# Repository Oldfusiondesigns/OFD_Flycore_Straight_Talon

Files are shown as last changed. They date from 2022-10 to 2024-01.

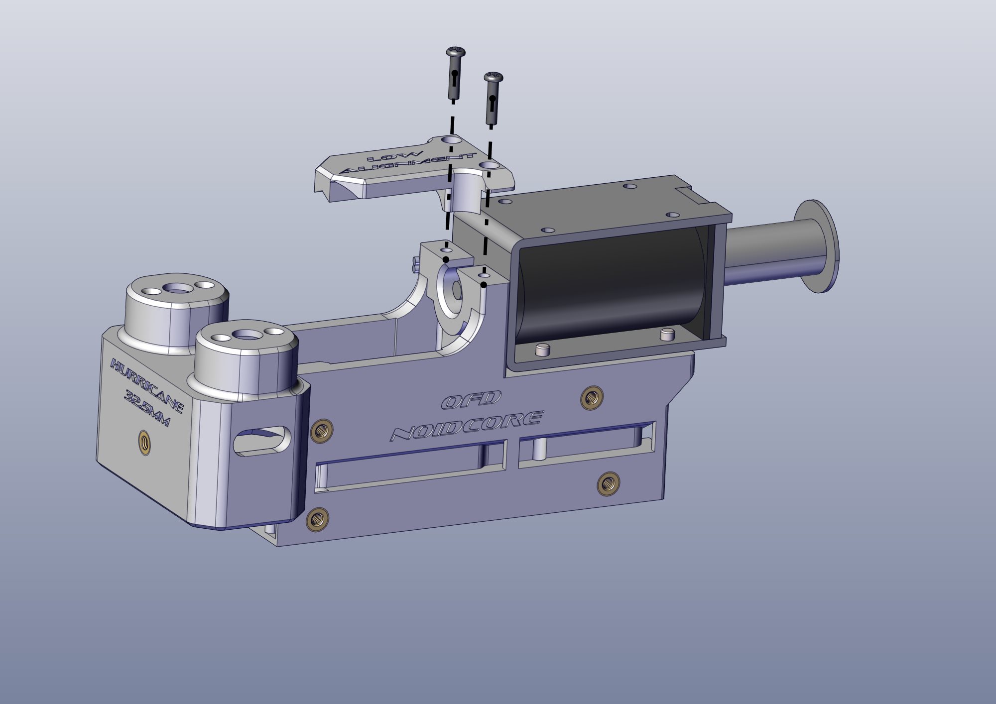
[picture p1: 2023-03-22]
Images/dart guide.jpg

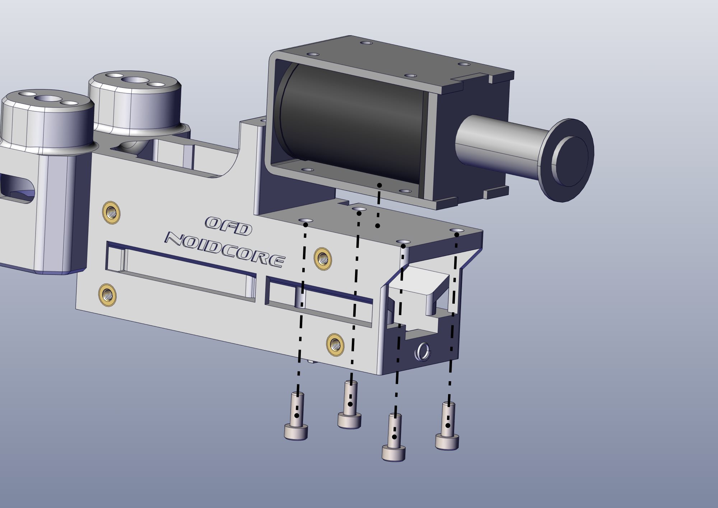
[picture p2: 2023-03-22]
Images/noid install.jpg

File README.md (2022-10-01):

**What is Flycore?**

· Flycore is a 90% complete blaster awaiting your
new shell, design, or integration! I’ve done all
the work on flywheel spacing, pusher
mechanisms, and even a complete magwell with
detent or release!

· The goal of Flycore is to allow designers new
and old to focus on creating exciting new
designs with a proven flywheel core that’s
simple to build and has compact geometry to
integrate

**Details**

· Compatible with ANY Flywheel (From FTW to
Banned Blasters)

· Angled Flycore compatible with BOTH Angled and Slim Angled
Talons (Nightingale mags) with the same mag
release/detent

·	Straight Flycore compatible with Talons and Tachi magazines

· Takes N20 Pushers (ROF from 300rpm/5dps up
to 3000rpm/50dps)(Recommended 2000rpm and under for best performance)

· Rear pusher position switch for controllable rate
of fire (wiring similar to 3 switch rapidstrike)

· Compatible with any 130 profile motor (can fit
132, 180s)

· Experimental topload capability

· Full steps provided to create your own new and
exciting blasters!

**Licensing and
Production**

· Flycore is license under CC-BY-SA-NC

· You have permission to print as many as you
like for yourself, and remix the files in any way
you like, but you CANNOT sell files or prints
without my permission or coming to an
agreement.

· If you wish to sell, please contact me so we can
arrange a licensing fee for a small percentage of
sale price

**Hardware List**

(2) 130 motors

(1) N20 Pusher Motor of your choice! (300-
3000rpm)

(4) m2x5mm motor screws

(8-9) M3 x 5mm diameter x 6mm deep heat set inserts (longer ones may not work)

(6) M2.6x12mm toy screws

(1) M2.6x10mm toy screw (Optional)

(1) Cherry DB2 style switch for pusher position
(Optional)

(1) Spring 20mm in length less than 7mm in diameter for mag release (Recommend McMaster 9657K297 Trimmed to ~20-22mm)

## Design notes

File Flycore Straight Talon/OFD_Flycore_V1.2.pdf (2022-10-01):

# OFD

# FLYCORE

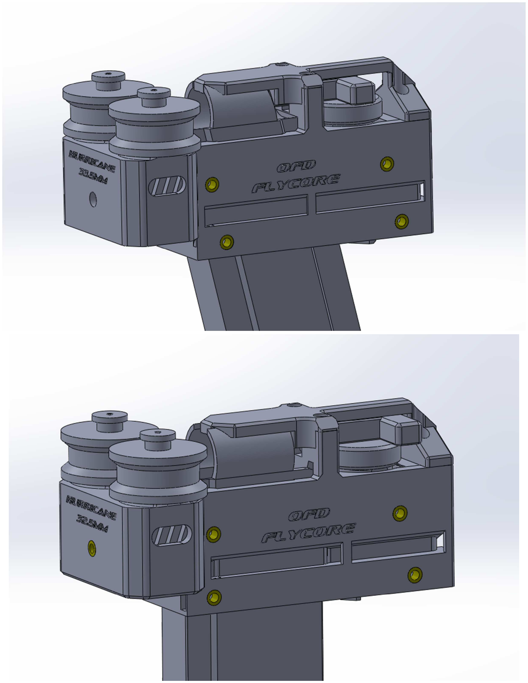
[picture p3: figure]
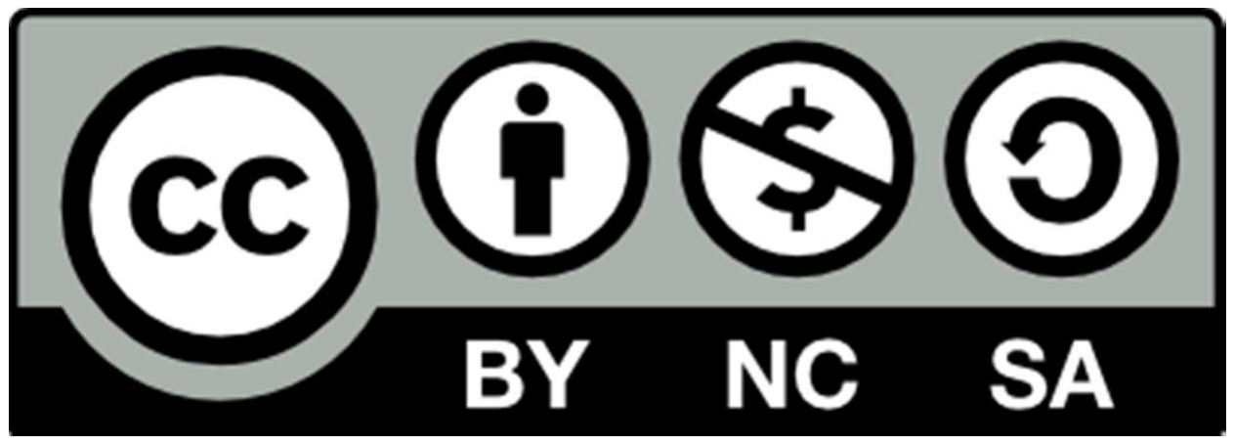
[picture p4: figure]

What is Flycore?
- Flycore is a 90% complete blaster awaiting your new shell, design, or integration! I’ve done all the work on flywheel spacing, pusher mechanisms, and even a complete magwell with detent or release!
- The goal of Flycore is to allow designers new and old to focus on creating exciting new designs with a proven flywheel core that’s simple to build and has compact geometry to integrate

Details
- Compatible with ANY Flywheel (From FTW to Banned Blasters)
- Angled Flycore compatible with BOTH Angled and Slim Angled Talons (Nightingale mags) with the same mag release/detent
- Straight Flycore compatible with Talons and Tachi magazines
- Takes N20 Pushers (ROF from 300rpm/5dps up to 3000rpm/50dps) (Recommended 2000rpm and under for best performance)
- Rear pusher position switch for controllable rate of fire (wiring similar to 3 switch rapidstrike)
- Compatible with any 130 profile motor (can fit 132, 180s)
- Experimental topload capability
- Full steps provided to create your own new and exciting blasters!

Licensing and
Production
- Flycore is licensed under CC-BY-SA-NC: https://creativecommons.org/licenses/by-nc-sa/2.0/
- You have permission to print as many as you like for yourself, and remix the files in any way you like with attribution, but you CANNOT sell files or prints without my permission or coming to an agreement.

Hardware List

(2) 130 motors
(1) N20 Pusher Motor of your choice! (300-3000rpm)
(4) m2x5mm motor screws
(8-9) M3 x 5mm diameter x 6mm deep heat set inserts (longer ones may not work)
(6) M2.6x12mm toy screws
(1) M2.6x10mm toy screw (Optional)
(1) Cherry DB2 style switch for pusher position (Optional)
(1) Spring 20mm in length less than 7mm in diameter for mag release (Recommend McMaster 9657K297 Trimmed to ~20-22mm)

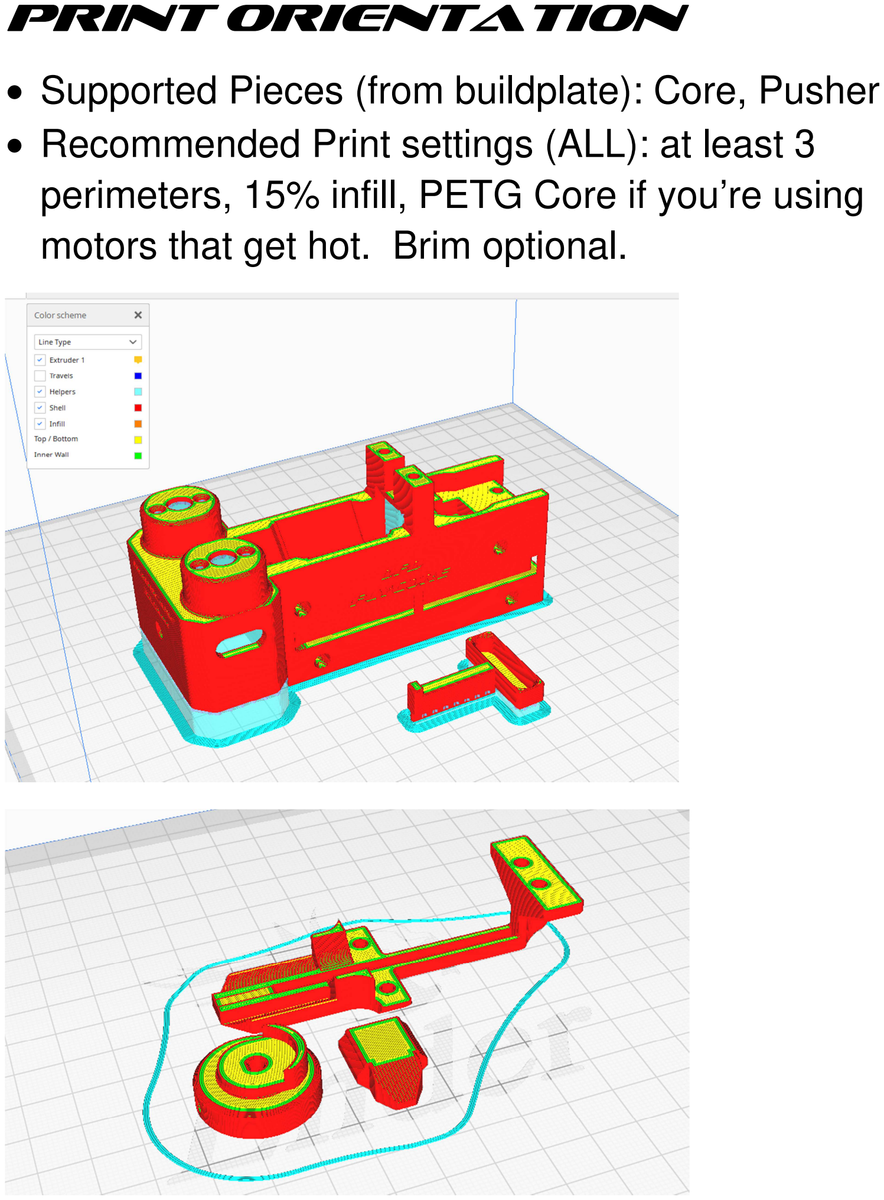
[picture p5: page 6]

Print Orientation
- Supported Pieces (from buildplate): Core, Pusher
- Recommended Print settings (ALL): at least 3 perimeters, 15% infill, PETG Core if you’re using motors that get hot. Brim optional.

Assembly

Step 1: Install heatsets

TIP: Trim off any flashing inside and outside the core to prevent installation issues

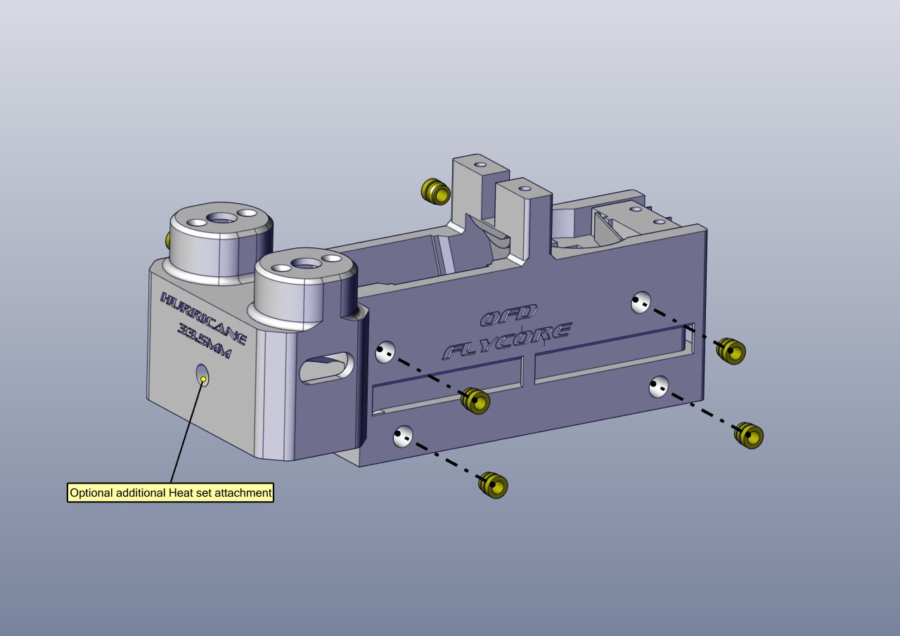
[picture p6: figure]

Step 2: Install N20

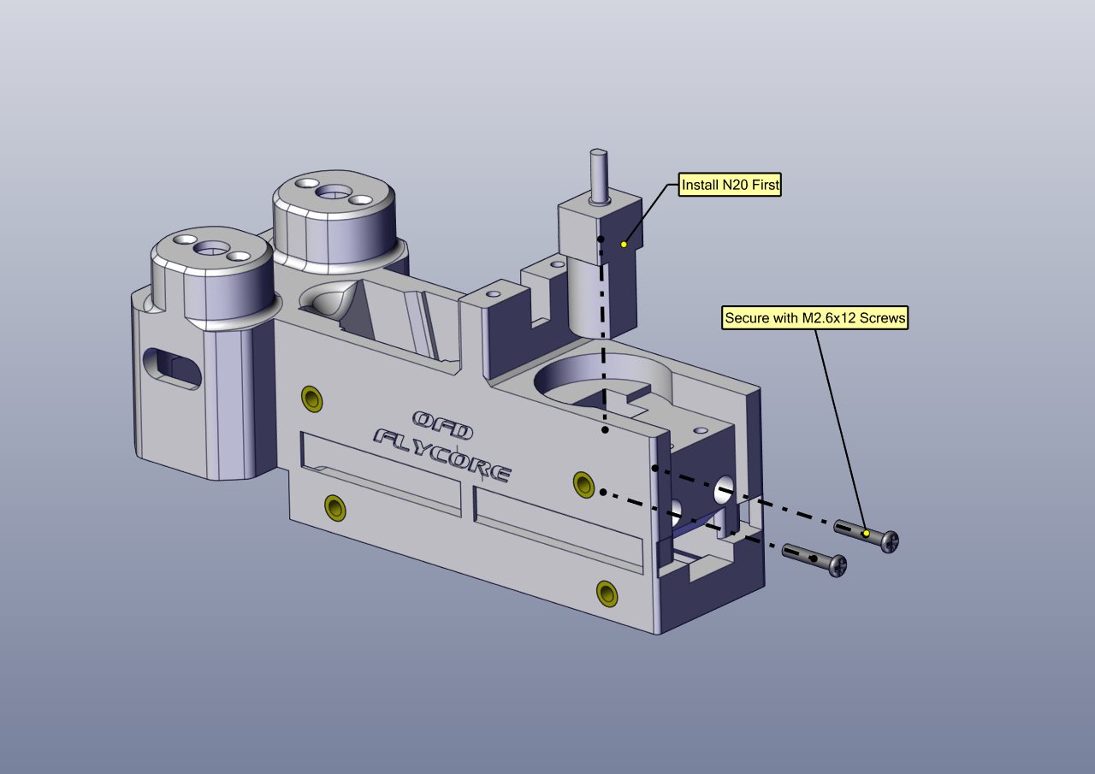
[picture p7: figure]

Step 3: Install Pusher Wheel

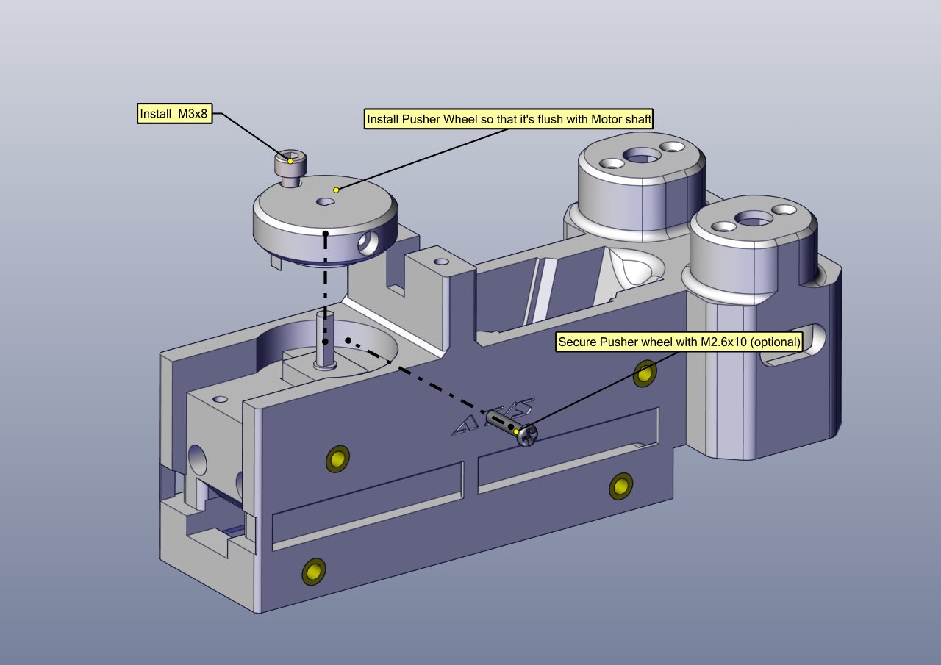
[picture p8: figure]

Step 4: Pusher Assembly Installation

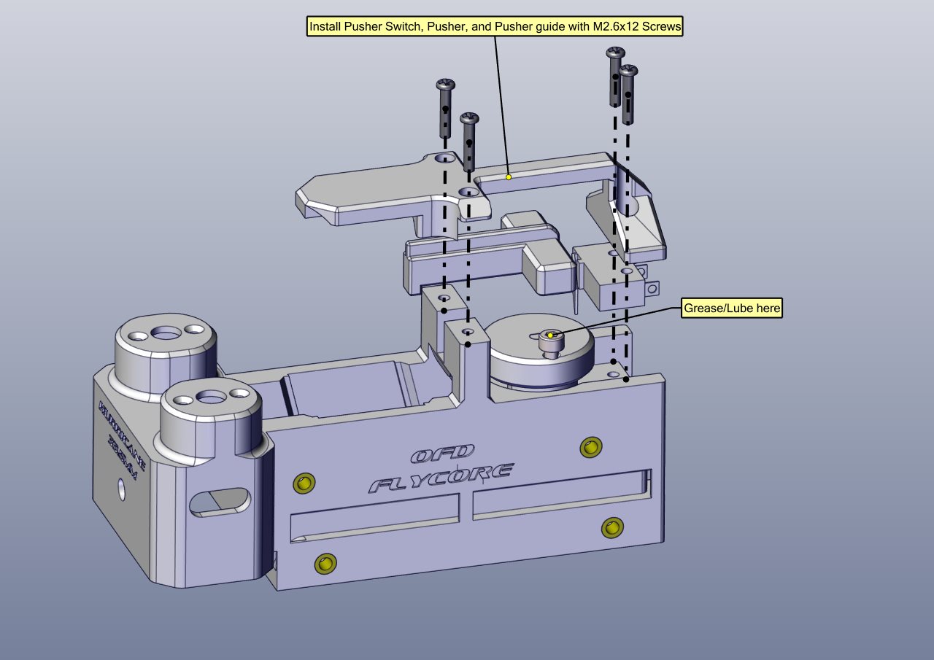
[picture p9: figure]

Step 5: Mag Release Installation

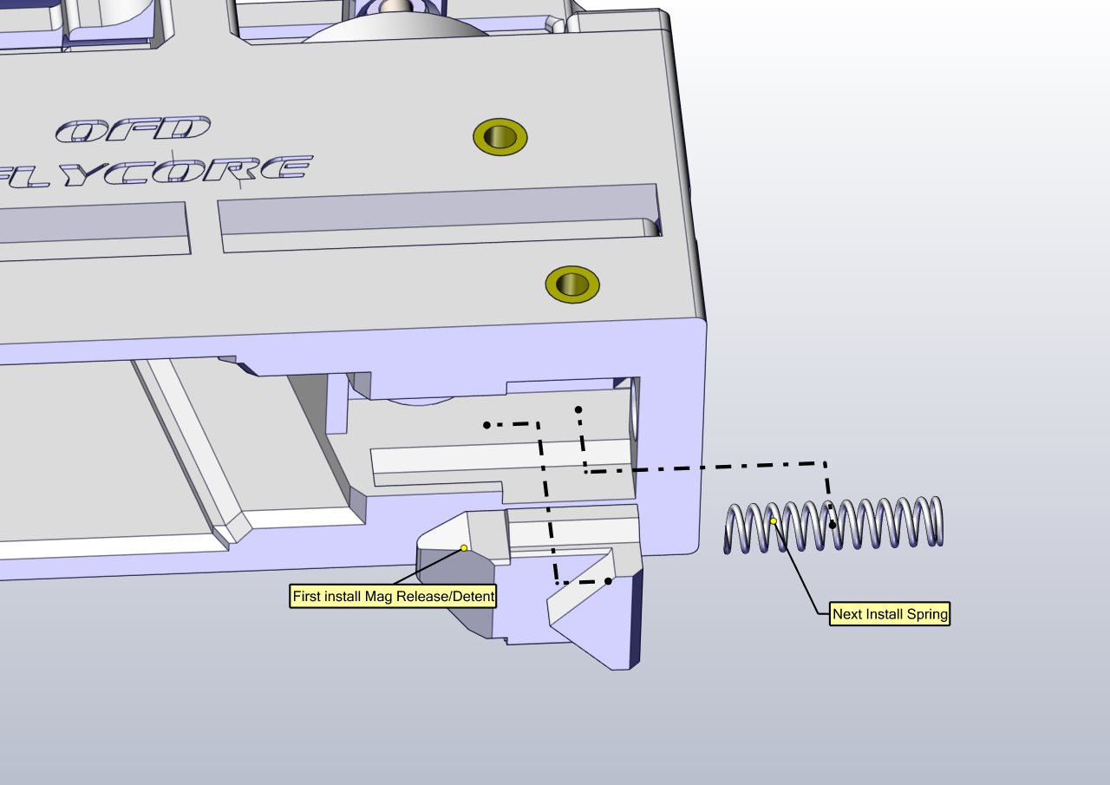
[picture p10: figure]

Step 6: Motor and Flywheel Installation

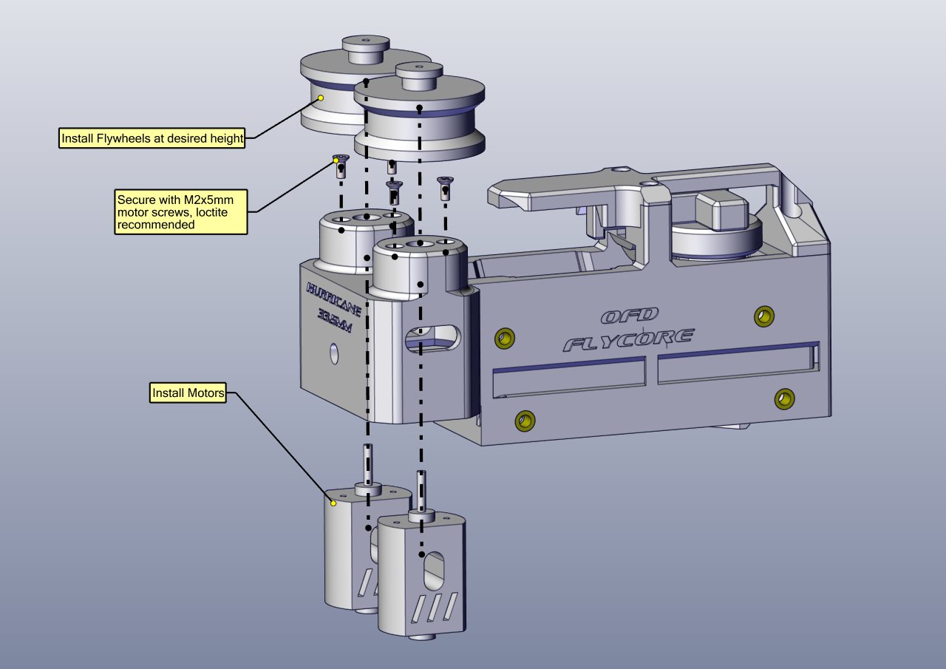
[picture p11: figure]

FAQ
- My N20 doesn’t seem like it’s activating the pusher switch!
a)If this is the case, bend the N20 switch arm slightly outward until it activates the switch when the pusher is fully back
- My 2000 or 3000 rpm pusher is running away, or won’t brake when I release the trigger!
a)In my testing these motors don’t have enough torque to overcome their own inertia and brake within a cycle, so if you want to run this high ROF, I’d recommend not worrying about including a pusher switch.
- My slim angled talons aren’t feeding right!
a)In our testing, slim angled talons can be picky about darts and magazine cleanliness, especially at higher rates of fire, so YMMV!
- I have more questions, or my questions aren’t listed here!
a)No worries! Feel free to reach out to me on Etsy, or my discord: ag04#6231

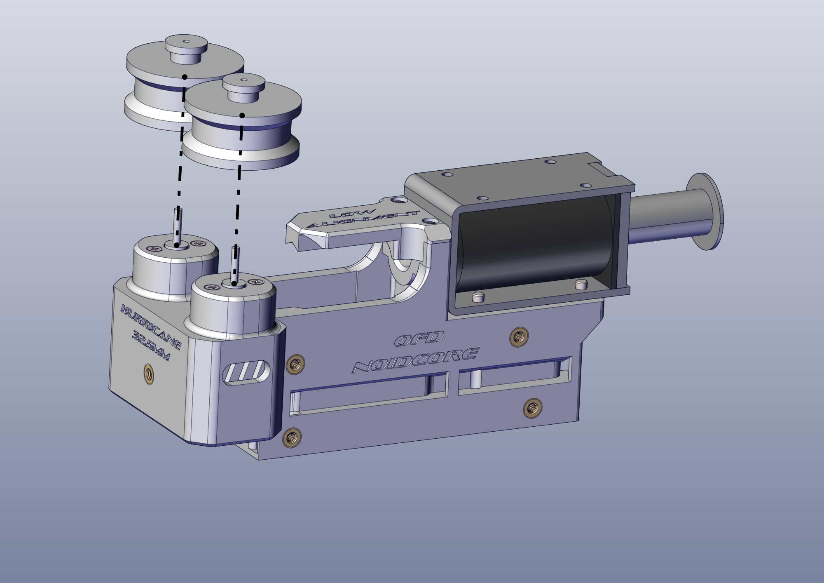
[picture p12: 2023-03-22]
Images/wheels.jpg

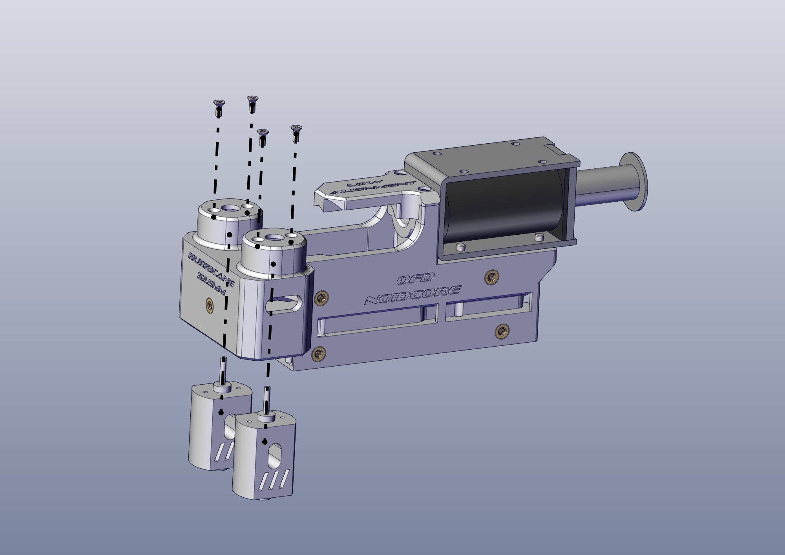
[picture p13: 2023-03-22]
Images/motor screws.jpg

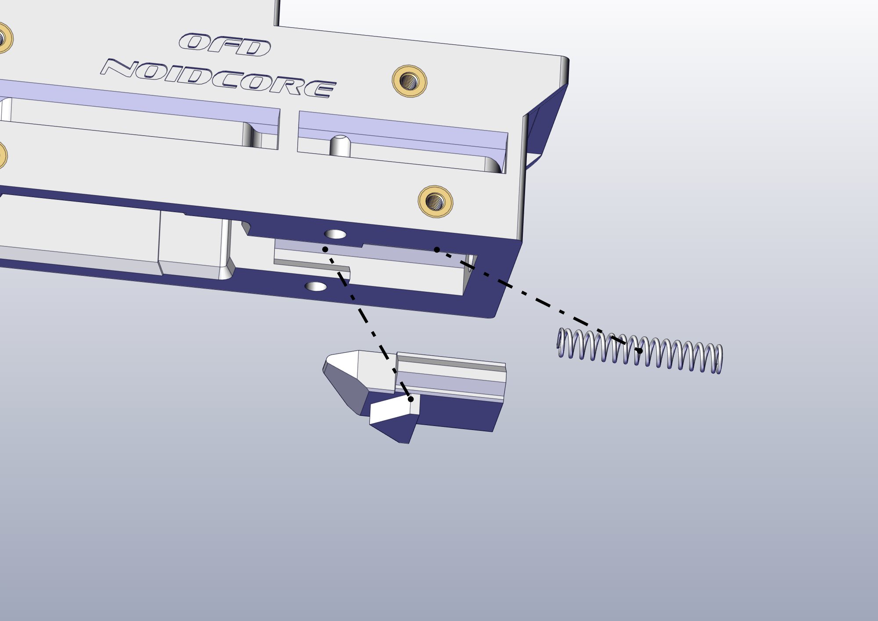
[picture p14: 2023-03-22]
Images/spring detent.jpg

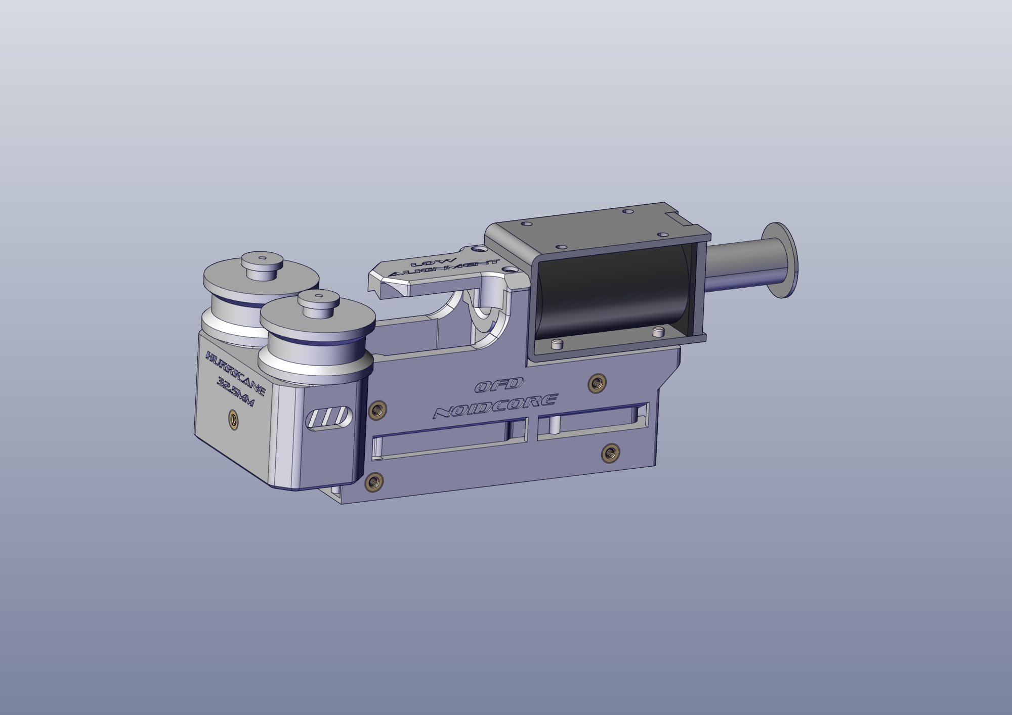
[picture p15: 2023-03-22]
Images/OFD_NOIDCORE_HURR_STRAIGHT_V1.jpg

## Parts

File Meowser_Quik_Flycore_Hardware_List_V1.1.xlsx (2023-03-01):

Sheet: Revision tracking
Changelog
Revision | Date | Changes
V1.0 | 2022-10-14 | Initial Release
V1.1 | 2023-03-01 | BOM corrections, additions, verification

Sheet: Flycore Angled+Straight
FLYCORE ANGLED/STRAIGHT BOM (NO BLASTER)
Priority | Category | Part | Qty | Description
REQUIRED | HARDWARE | M3 Heatsets (5-5.4mm Dia, <6.5mm length) | 9 | (8) Quik (9) Meowser
 |  | M3x8mm Socket Head Cap Screw | 1 | N20 Pusher wheel set screw
 |  | M2x4-5mm motor screws | 4 | Motor screws
 |  | M2.6x10mm toy screws | 1 | Pusher wheel set screw
 |  | M2.6x12mm toy screws | 6 | (4) pusher guide (2) optional N20 motor set screws
 |  | Mcmaster 9657k297 Trimmed to 20-22mm OR alt part 9657K282(pending update) | 1 | Mag release spring
 | ELECTRONICS | 130-180 motors | 2 | 130 Motors for best vent fitment
 |  | Cherry DB2 style switch with lever | 1 | Pusher postion switch
 |  | N20 Pusher Motor | 1 | Recommend under 1000 rpm and under for live center and 2000 rpm for highest reliable ROF

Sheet: Meowser
MEOWSER BOM (NO FLYCORE)
Priority | Category | Part | Qty | Description
REQUIRED | HARDWARE | M2x4-5mm motor screws | 4 | Rear sight, Volt meter
 |  | M2.6x12mm Toy Screws | 4 | Muzzle on square barrel, Mag release, Switch pack
 |  | M3x8mm Socket Head Cap Screws | 14 | (9) body, (3) barrel
 |  | M3x6-8mm Button Head Screw | 1 | LH Grip
 |  | M3x8-10mm Battery door screw | 1 | Battery Door
 |  | M3 Heatsets (5-5.4mm Dia, <6.5mm length) | 5 | (3) Barrel (2) Grip/Batt door
 |  | Mcmaster 9657k297 Trimmed to 20-22mm OR alt part 9657K282(pending update) | 1 | Trigger Spring
 | ELECTRONICS | 21A Omron style switch without Lever | 1 | Rev switch
 |  | Cherry DB2 style switch without lever | 1 | Pusher switch
 |  | 22 Ga wire | 1 | Pusher, Trigger Switch
 |  | 18 Ga wire | 1 | Motors, Rev Switch, Battery
 |  | XT30 connector | 1 | Battery Connector
 |  | Heatshrink | 1 | Heatshrink for xt30
OPTIONAL | HARDWARE | M3x12 Socket Head Cap Screws | 4 | Fidlock Mounts
 |  | .078"/2mm Fiber optic | 1
 |  | Fidlock M | 2 | approx 50mm total for sights
 | ELECTRONICS | .28" Battery Voltage meter | 1
OPTIONAL DL-44 Kit | HARDWARE | M3x12 Socket Head Cap Screws | 4 | Scope mounting plate
 |  | M3 Heatsets | 2 | Scope mount assembly
 |  | M3x8-10mm thumb screws OR M3x8 Socket Head Cap Screws | 2 | Scope mount side
 |  | M3x8 Socket Head Cap Screws | 6 | (4) Scope rings (2) upper mount
OPTIONAL Tactical Kit | HARDWARE | M2x4-5mm motor screws | 1 | Printed RMR reticle set screw
 |  | M3x8 Socket Head Cap Screws | 2 | Printed RMR

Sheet: Flycore+Meowser
MEOWSER + FLYCORE STRAIGHT BOM
Priority | Category | Part | Qty | Description
REQUIRED | HARDWARE | M2x4-5mm motor screws | 8 | (2) Rear sight, (2)Volt meter/blank plate (4) Motors
 |  | M2.6x10mm toy screws | 1 | N20 pusher wheel set screw
 |  | M2.6x12mm toy Screws | 10 | (2) Muzzle on square barrel, (4) Flycore pusher guide, (2) N20 Set screws, (1) Mag release (1) Switch pack
 |  | M3x8mm Socket Head Cap Screws | 13 | (9) body, (3) barrel (1) Flycore Pusher Wheel
 |  | M3x6-8mm Button Head Screw | 1 | RH Grip
 |  | M3x8-10mm Battery door thumb screw | 1 | Battery Door
 |  | M3 Heatsets (5-5.4mm Dia, <6.5mm length) | 14 | (9) Flycore Straight (3) Barrel (2) Grip/Batt door
 |  | Mcmaster 9657k297 Trimmed to 20-22mm OR alt part 9657K282(pending update) | 2 | Trigger Spring, Flycore mag release
 | ELECTRONICS | 130-180 motors | 2 | 130 Motors for best vent fitment
 |  | N20 Pusher Motor | 1 | Recommend 1000 rpm and under for live center and 2000 rpm for highest reliable ROF (2k untested on high ROF Tachis)
 |  | 21A Omron style switch without Lever | 1 | Rev switch
 |  | Cherry DB2 style switch without lever | 1 | Pusher switch
 |  | Cherry DB2 style switch with lever | 1 | Pusher postion switch
 |  | 22 Ga wire | 1 | Pusher, Trigger Switch
 |  | 18 Ga wire | 1 | Motors, Rev Switch, Battery
 |  | XT30 connector | 1 | Battery Connector
 |  | Heatshrink | 1 | Heatshrink for xt30
OPTIONAL | HARDWARE | M3x12 Socket Head Cap Screws | 4 | Fidlock Mounts
 |  | .078"/2mm Fiber optic | 1 | approx 50mm total for sights
 |  | Fidlock M | 2
 | ELECTRONICS | .28" Battery Voltage meter | 1
OPTIONAL DL-44 Kit | HARDWARE | M3x12 Socket Head Cap Screws | 4 | Scope mounting plate
 |  | M3 Heatsets | 2 | Scope mount assembly
 |  | M3x8-10mm thumb screws OR M3x8 Socket Head Cap Screws | 2 | Scope mount side
 |  | M3x8 Socket Head Cap Screws | 6 | (4) Scope rings (2) upper mount
OPTIONAL Tactical Kit | HARDWARE | M2x4-5 motor screw | 1 | Printed RMR reticle set screw
 |  | M3x8 Socket Head Cap Screws | 2 | Printed RMR

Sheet: Quik
QUIK BOM (NO FLYCORE)
Priority | CATEGORY | Part | Qty | Description
REQUIRED | HARDWARE | M2x4-5mm motor screws | 2 | Rear sight
 |  | M2.6x12mm Toy Screws | 1 | switch plate
 |  | M3x8mm Socket Head Cap Screws | 9 | (8) body, (1) switch plate
 |  | M3x8-10mm Battery door screw | 1 | Battery Door
 |  | M3 Heatsets (5-5.4mm Dia, <6.5mm length) | 2 | (1) switch plate (1) batt door
 |  | Mcmaster 9657k297 Trimmed to 20-22mm | 1 | Trigger Spring
 | ELECTRONICS | 21A Omron style switch without Lever | 1 | Rev switch
 |  | Cherry DB2 style switch with lever | 1 | Pusher switch
 |  | 22 Ga wire | 1 | Pusher, Trigger Switch
 |  | 18 Ga wire | 1 | Motors, Rev Switch, Battery
 |  | XT30 connector | 1 | Battery Connector
 |  | Heatshrink | 1 | Heatshrink for xt30
OPTIONAL | HARDWARE | M3x12 Socket Head Cap Screws | 4 | Fidlock Mounts
 |  | Fidlock M | 2
 | ELECTRONICS | .28" Battery Voltage meter | 1

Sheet: Flycore+Quik
QUIK + FLYCORE ANGLED BOM
Priority | Category | Part | Qty | Description
REQUIRED | HARDWARE | M2x4-5mm motor screws | 6 | (2) Rear sight, (4) Motor screws
 |  | M2.6x10mm toy screws | 1 | N20 pusher wheel set screw
 |  | M2.6x12mm Toy Screws | 1 | (4) pusher guide (2) optional n20 set screws (1) switch plate
 |  | M3x8mm Socket Head Cap Screws | 10 | (8) body, (1) switch plate (1) Flycore pusher wheel
 |  | M3x8-10mm battery door thumb screw | 1 | Battery Door
 |  | M3 Heatsets (5-5.4mm Dia, <6.5mm length) | 10 | (1) switch plate (1) batt door (8) Flycore Angled
 |  | Mcmaster 9657k297 Trimmed to 20-22mm OR alt part 9657K282(pending update) | 2 | (1) Trigger spring (1) Mag release spring
 | ELECTRONICS | 130-180 motors | 2 | 130 Motors for best vent fitment
 |  | N20 Pusher Motor | 1 | Recommend 1000 rpm and under for live center and 2000 rpm max for highest reliable ROF
 |  | 21A Omron style switch without Lever | 1 | Rev switch
 |  | Cherry DB2 style switch with lever | 2 | (1) Pusher switch (1) Trigger switch
 |  | 22 Ga wire | 1 | Pusher, Trigger Switch
 |  | 18 Ga wire | 1 | Motors, Rev Switch, Battery
 |  | XT30 connector | 1 | Battery Connector
 |  | Heatshrink | 1 | Heatshrink for xt30
OPTIONAL | HARDWARE | M3x12 Socket Head Cap Screws | 4 | Fidlock Mounts
 |  | Fidlock M | 2
 | ELECTRONICS | .28" Battery Voltage meter | 1

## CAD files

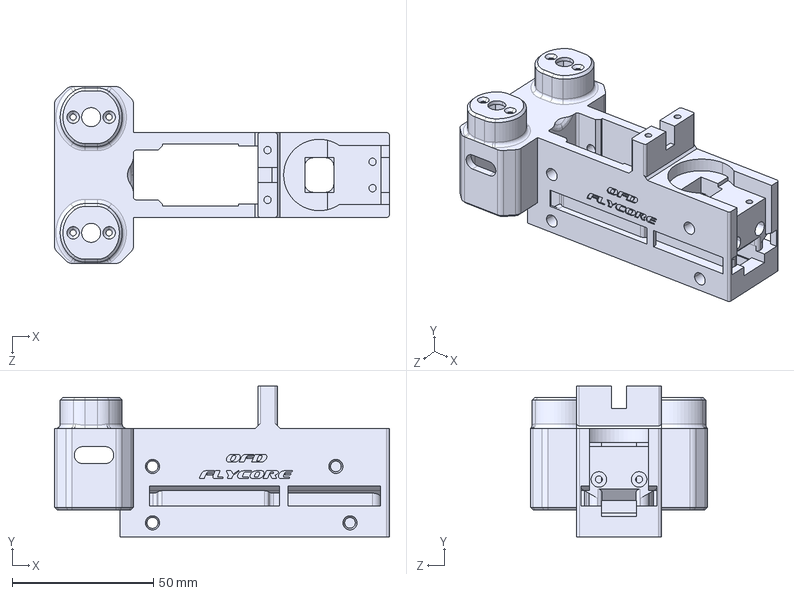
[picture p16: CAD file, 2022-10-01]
Flycore Straight Talon/STEPs/OFD_FLYCORE_STRAIGHT_FULL_41MM_V1.STEP
118.8 x 53.5 x 62.7 mm

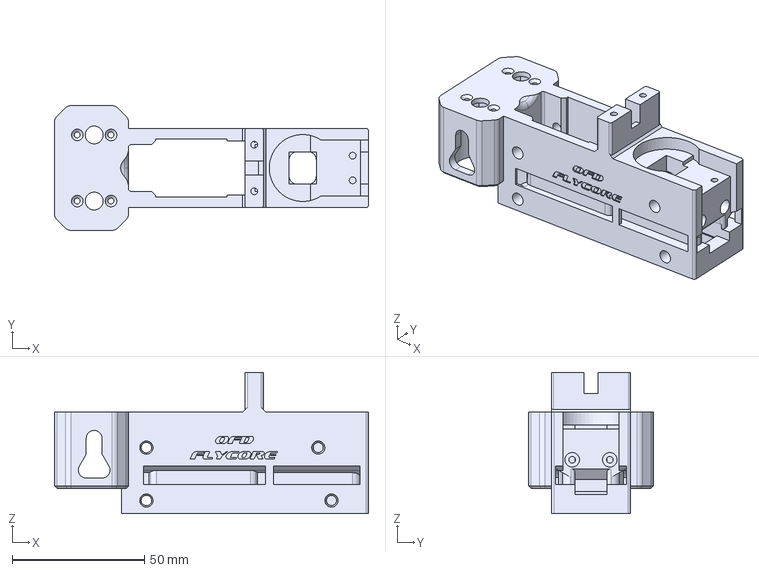
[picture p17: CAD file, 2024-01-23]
Flycore Straight Talon/STEPs/OFD_FLYCORE_STRAIGHT_TRACEUR_25MM_V1.step
118.8 x 47.2 x 53.5 mm

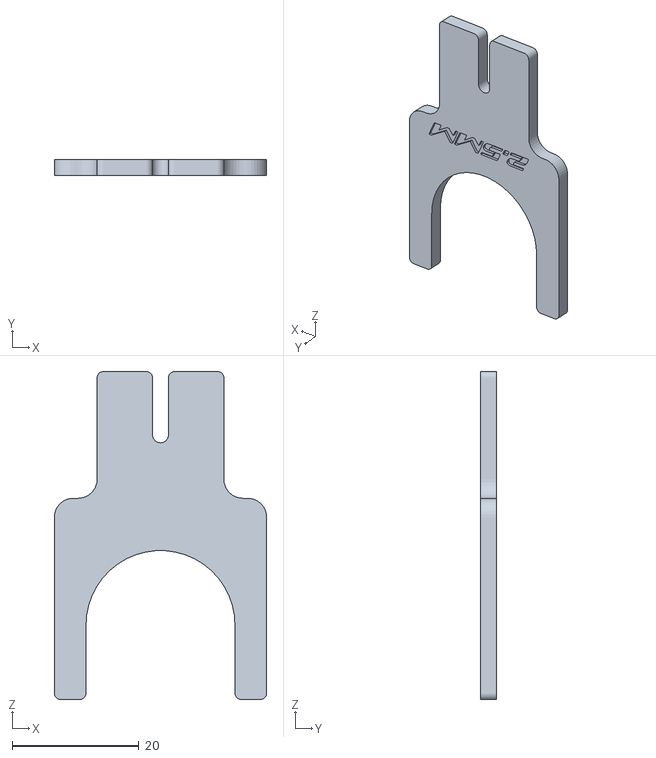
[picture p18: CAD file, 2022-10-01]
Flycore Straight Talon/STLs/Flywheel_Spacers/OFD_Flywheel_Spacer_2.5mm_V1.STL
33.5 x 2.50 x 51.8

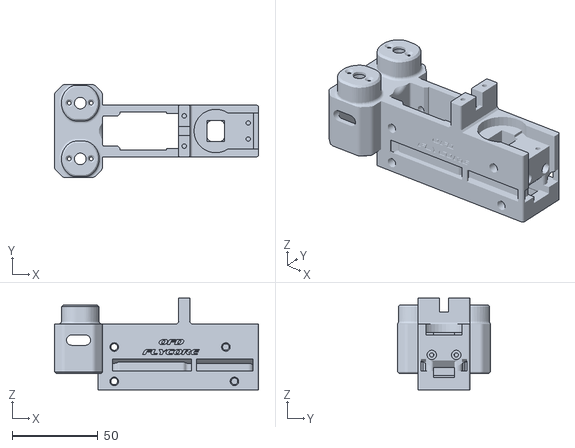
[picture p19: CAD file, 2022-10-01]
Flycore Straight Talon/STLs/OFD_FLYCORE_STRAIGHT_HURR_32.5MM_V1.stl
118.8 x 54.2 x 53.5

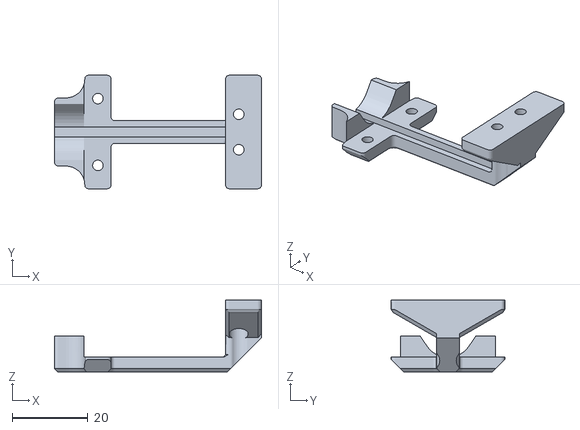
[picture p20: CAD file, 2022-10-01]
Pusher_Guide_Top_Load_Experimental_V1.STL
54.7 x 30.0 x 19.0

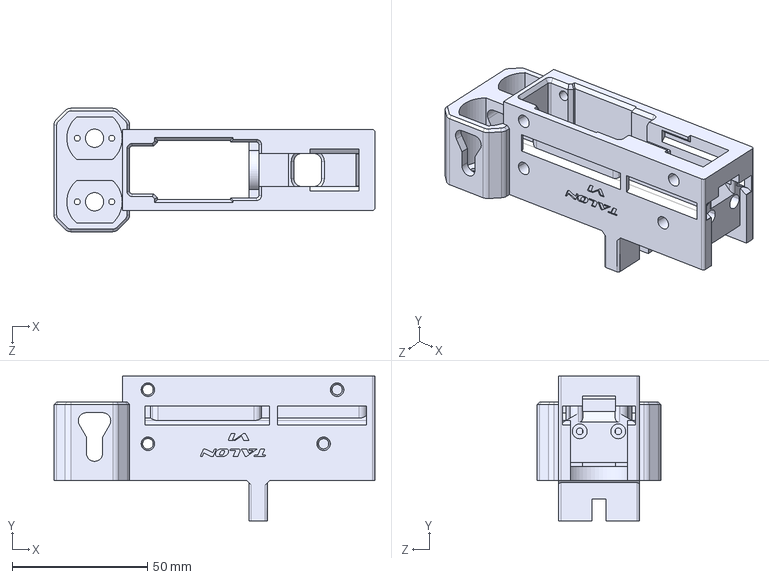
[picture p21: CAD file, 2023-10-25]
Flycore Straight Talon/STEPs/OFD_FLYCORE_STRAIGHT_FTW_23.5MM_V1.STEP
118.8 x 53.5 x 45.7 mm

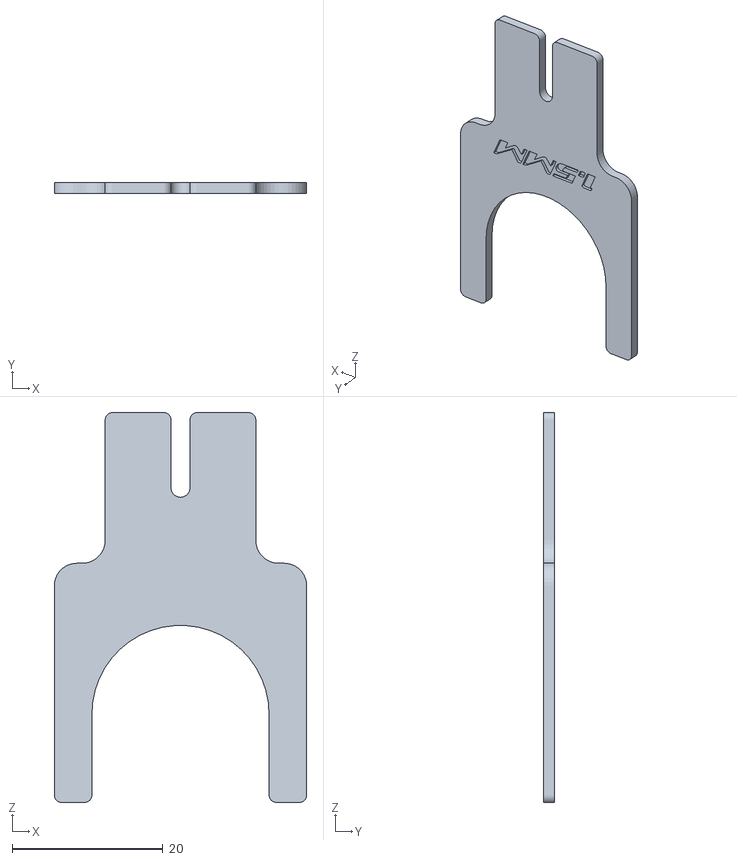
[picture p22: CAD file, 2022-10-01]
Flycore Straight Talon/STLs/Flywheel_Spacers/OFD_Flywheel_Spacer_1.5mm_V1.STL
33.5 x 1.50 x 51.8

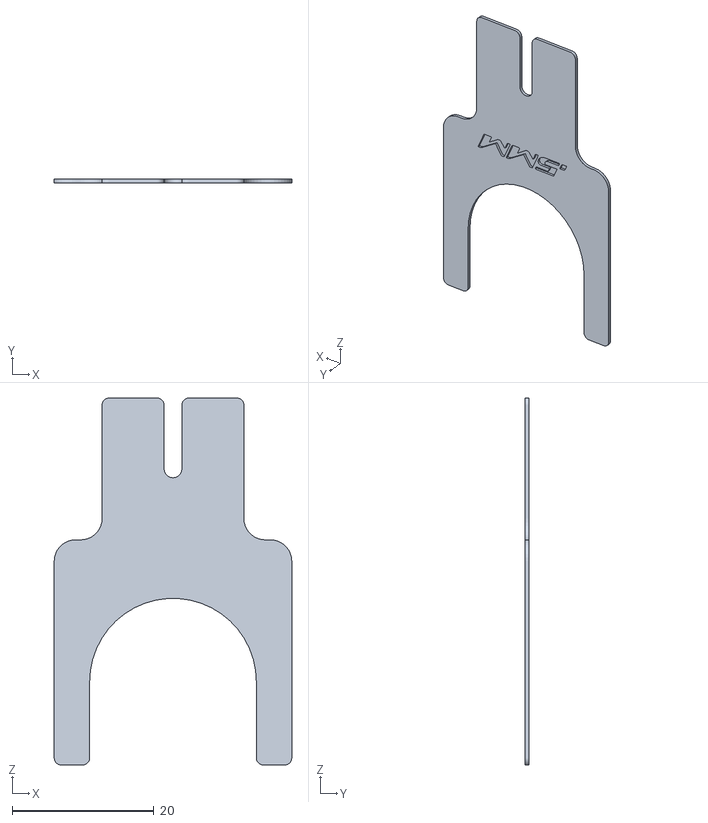
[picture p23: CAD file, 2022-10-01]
Flycore Straight Talon/STLs/Flywheel_Spacers/OFD_Flywheel_Spacer_.5mm_V1.STL
33.5 x 0.5 x 51.8

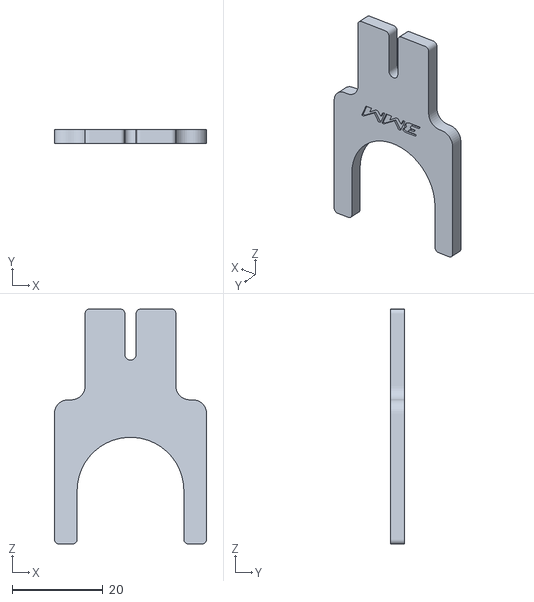
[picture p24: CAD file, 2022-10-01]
Flycore Straight Talon/STLs/Flywheel_Spacers/OFD_Flywheel_Spacer_3mm_V1.STL
33.5 x 3.00 x 51.8

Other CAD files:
Flycore Straight Talon/STEPs/OFD_FLYCORE_STRAIGHT_FULL_39.5MM_V1.STEP
Flycore Straight Talon/STEPs/OFD_FLYCORE_STRAIGHT_FULL_41.5MM_V1.STEP
Flycore Straight Talon/STEPs/OFD_FLYCORE_STRAIGHT_FULL_43MM_V1.STEP
Flycore Straight Talon/STEPs/OFD_FLYCORE_STRAIGHT_FULL_40.5MM_V1.STEP
Flycore Straight Talon/STEPs/OFD_FLYCORE_STRAIGHT_FULL_40MM_V1.STEP
Flycore Straight Talon/STEPs/OFD_FLYCORE_STRAIGHT_FULL_42MM_V1.STEP
Flycore Straight Talon/STLs/OFD_FLYCORE_STRAIGHT_HURR_33.5MM_V1.stl
Flycore Straight Talon/STEPs/OFD_FLYCORE_STRAIGHT_NGALE_19.5MM_V1.STEP
Flycore Straight Talon/STEPs/Pusher_Guide_Top_Load_Experimental_V1.STEP
Flycore Straight Talon/STEPs/OFD_FLYCORE_STRAIGHT_FTW_22.5MM_V1.STEP
Flycore Straight Talon/STEPs/OFD_FLYCORE_STRAIGHT_FTW_22MM_V1.STEP
Flycore Straight Talon/STEPs/OFD_FLYCORE_STRAIGHT_FTW_23MM_V1.STEP
Flycore Straight Talon/STEPs/OFD_FLYCORE_STRAIGHT_HURR_33MM_V1.STEP
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
